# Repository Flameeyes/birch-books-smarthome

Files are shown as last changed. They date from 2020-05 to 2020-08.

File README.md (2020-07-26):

<!--
SPDX-FileCopyrightText: 2020 The birch-books-smarthome Authors

SPDX-License-Identifier: MIT
-->

# Birch Books Smart Home

Lighting up the scene

This repository contains code, schematics, documentation and notes to implement a
MCU-controlled LED lights system for the [LEGO Creator Bookshop
set](https://www.lego.com/en-gb/product/bookshop-10270) (10270).

## Further References

Refer to my [blog posts](https://flameeyes.blog/tag/birch-books/) for details.

You can see some pictures of the results on [my Flickr
album](https://www.flickr.com/photos/flameeyes/albums/72157714292772872).

## License

Copyright 2020 The birch-books-smarthome authors.

Permission is hereby granted, free of charge, to any person obtaining a copy of this
software and associated documentation files (the "Software"), to deal in the Software
without restriction, including without limitation the rights to use, copy, modify,
merge, publish, distribute, sublicense, and/or sell copies of the Software, and to
permit persons to whom the Software is furnished to do so, subject to the following
conditions:

The above copyright notice and this permission notice shall be included in all copies or
substantial portions of the Software.

THE SOFTWARE IS PROVIDED "AS IS", WITHOUT WARRANTY OF ANY KIND, EXPRESS OR IMPLIED,
INCLUDING BUT NOT LIMITED TO THE WARRANTIES OF MERCHANTABILITY, FITNESS FOR A PARTICULAR
PURPOSE AND NONINFRINGEMENT. IN NO EVENT SHALL THE AUTHORS OR COPYRIGHT HOLDERS BE
LIABLE FOR ANY CLAIM, DAMAGES OR OTHER LIABILITY, WHETHER IN AN ACTION OF CONTRACT, TORT
OR OTHERWISE, ARISING FROM, OUT OF OR IN CONNECTION WITH THE SOFTWARE OR THE USE OR
OTHER DEALINGS IN THE SOFTWARE.

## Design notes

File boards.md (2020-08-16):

<!--
SPDX-FileCopyrightText: 2020 The birch-books-smarthome Authors

SPDX-License-Identifier: MIT
-->

# Board Description

For the Birch Books Smart Home project I decided to design the system with two type of
boards: an actuation board, and a controller board. The reason for the split design is
that the controller board can be replaced with alternative implementations without
requiring a new set of wiring for the LEDs.

## Actuation Board

The Actuation Board is a separate board component that bridges the logic in the
controller with the inputs and outputs, and can be used with different controller board
designs as well.

The actuation board is as simple as it can be:

  * 3× pushbuttons (`RST`, `TEST`, `FF`);
  * 3× 1kΩ resistors for pull-down;
  * 2× ULN2003AD Darlington Array;
  * 14× 47Ω resistors, or 2× bussed 7-port resistor networks, for the LEDs.

Two connectors are also present: a 1x20, breadboard compatible header to connect to the
controller board, and a 2×15 connector to connect to the LEDs.

### MCU Connector

| Pin(s) | Description |
| --- | --- |
| 1 | +5V DC |
|  2~15  | LED status (HIGH is ON) |
| 16 | FF input (HIGH is ON) |
| 17 | TEST input (HIGH is ON) |
| 18 | RST input (HIGH is ON)  |
| 19 | VIO (logic HIGH) |
| 20 | GND |

Note that the connector has both a fixed +5V and a VIO, to allow controller boards using
+3.3V CMOS levels for input/output.

As the board was originally designed for 8051 MCUs, the RST line is *active HIGH*, which
is unusual. To connect it to an active-low RST pin, consider using a NPN transistor.

## Controller Boards

Multiple controller boards are present in this repository, with different level of test.

### 8051/8052 (Partly Tested)

This is the original controller board. It was designed with an STC89C52 MCU in mind (a
modern 8052 implementation), and as such it has the UART marked as `ISP_STC` on board
itself.

It includes an optionally-populated CP2104 USB-to-UART chip (and related passives) to
make the programming easier. But it has not been tested since I failed to program a new
chip with the correct firmware.

The firmware for this board is in `8051/`.

### Trinket M0 with MCP23016/17 (In Use)

This version of the controller is designed to work with an [Adafruit Trinket
M0](https://www.adafruit.com/product/3500) board on top.

There are two separate boards in the directory, which are based around the same design
and firmware, but with different GPIO Expanders on them. It's recommended to use the
**MCP23017** version, which has two fewer components and is more reliable.

Both boards have marking and can be technically adapted to use any MCU that supports I²C
and has drivers for the MCP23016/17 series adapters. The needed lines are +5V, VIO (e.g.
3.3V), GND, SDA, SCL, ¬RST.

The firmware for this board is in `circuitpython/`.

### ATmega48

This version of the controller is designed to work with
[ATmega48](https://www.microchip.com/wwwproducts/en/ATmega48) and
[ATmega328](https://www.microchip.com/wwwproducts/en/ATmega328) (the latter untested).

This board is a compromise between the 8051 and Trinket M0 options: it include a simple
8-bit MCU, requiring no passive components, but also an inverter for the RST line.

The ISP header should be compatible with many ATmega programmers, as it exposes the SPI
bus together with the reset and power lines, and is configured as follows:

| Pin | Description |
| --- | --- |
|  1  | SIO |
|  2  | +5V |
|  3  | SCK |
|  4  | SDO |
|  5  | RST |
|  6  | GND |

Note that there is no CS line.

The firmware for this board is in `atmega48/` and should be **source** compatible with
ATmega328, but might require Makefile changes.

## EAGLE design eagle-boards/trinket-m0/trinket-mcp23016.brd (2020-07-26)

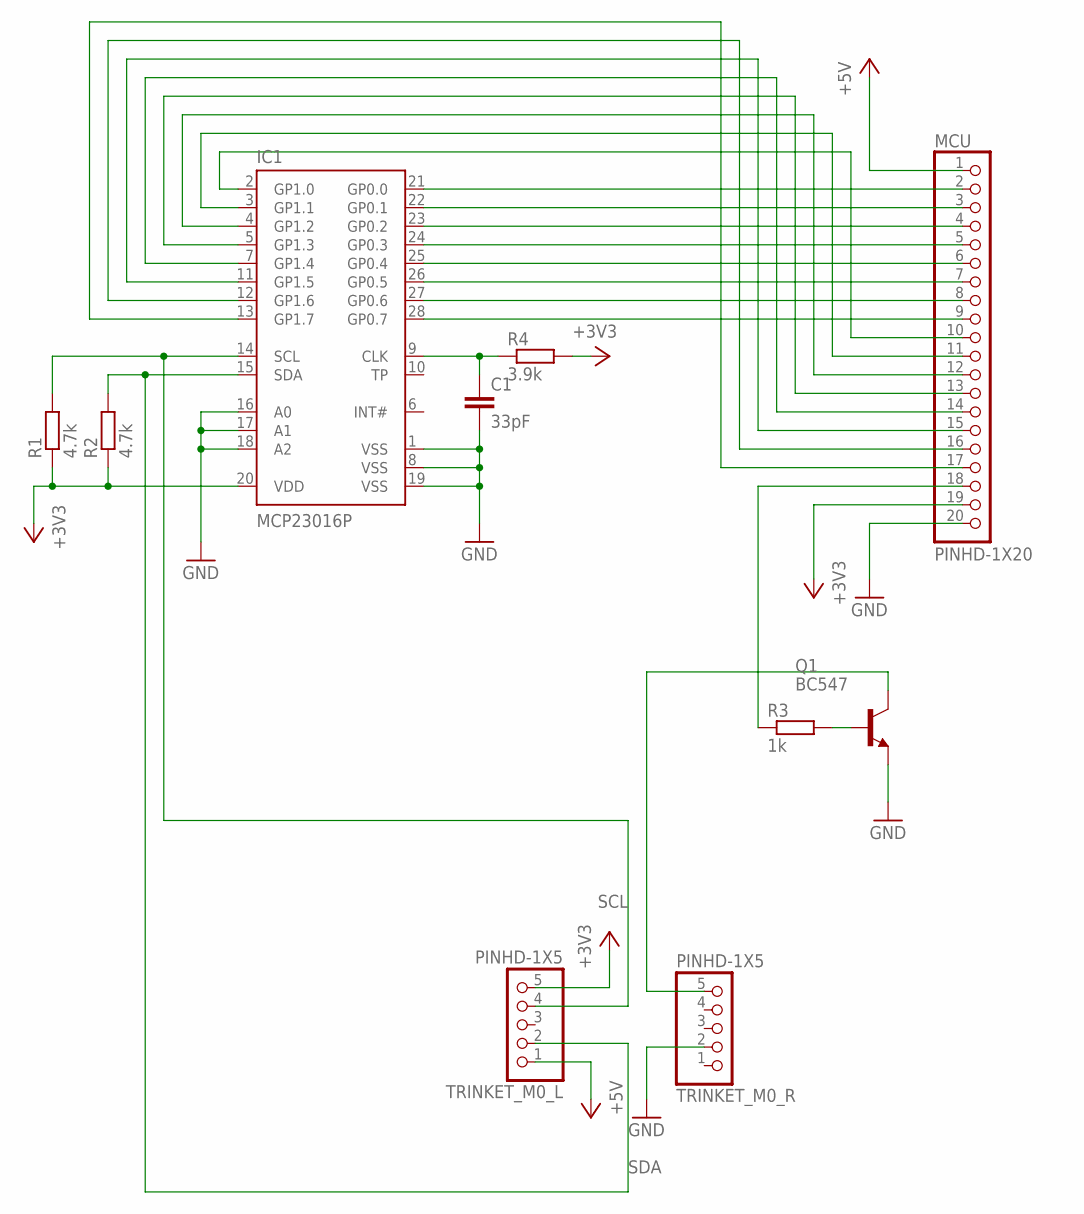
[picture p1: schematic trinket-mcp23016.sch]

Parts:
C1: 33pF; C025-025X050
IC1: MCP23016P; DIL28-3
MCU: PINHD-1X20; 1X20
Q1: BC547; TO92
R1, R2: 4.7k; 0207/10
R3: 1k; 0207/10
R4: 3.9k; 0207/10
TRINKET_M0_L, TRINKET_M0_R: PINHD-1X5; 1X05

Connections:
+3V3: IC1.20 (VDD), MCU.19, R1.1, R2.1, R4.2, TRINKET_M0_L.5
+5V: MCU.1, TRINKET_M0_L.1
GND: C1.2, IC1.1 (VSS), IC1.8 (VSS), IC1.16 (A0), IC1.17 (A1), IC1.18 (A2), IC1.19 (VSS), MCU.20, Q1.1 (E), TRINKET_M0_R.2
unnamed: IC1.21 (GP0.0), MCU.2
unnamed: IC1.22 (GP0.1), MCU.3
unnamed: IC1.23 (GP0.2), MCU.4
unnamed: IC1.24 (GP0.3), MCU.5
unnamed: IC1.25 (GP0.4), MCU.6
unnamed: IC1.26 (GP0.5), MCU.7
unnamed: IC1.27 (GP0.6), MCU.8
unnamed: IC1.28 (GP0.7), MCU.9
unnamed: IC1.2 (GP1.0), MCU.10
unnamed: IC1.3 (GP1.1), MCU.11
unnamed: IC1.4 (GP1.2), MCU.12
unnamed: IC1.5 (GP1.3), MCU.13
unnamed: IC1.7 (GP1.4), MCU.14
unnamed: IC1.11 (GP1.5), MCU.15
unnamed: IC1.12 (GP1.6), MCU.16
unnamed: IC1.13 (GP1.7), MCU.17
unnamed: Q1.2 (B), R3.2
unnamed: MCU.18, R3.1
unnamed: Q1.3 (C), TRINKET_M0_R.5
unnamed: C1.1, IC1.9 (CLK), R4.1
SCL: IC1.14 (SCL), R1.2, TRINKET_M0_L.4
SDA: IC1.15 (SDA), R2.2, TRINKET_M0_L.2

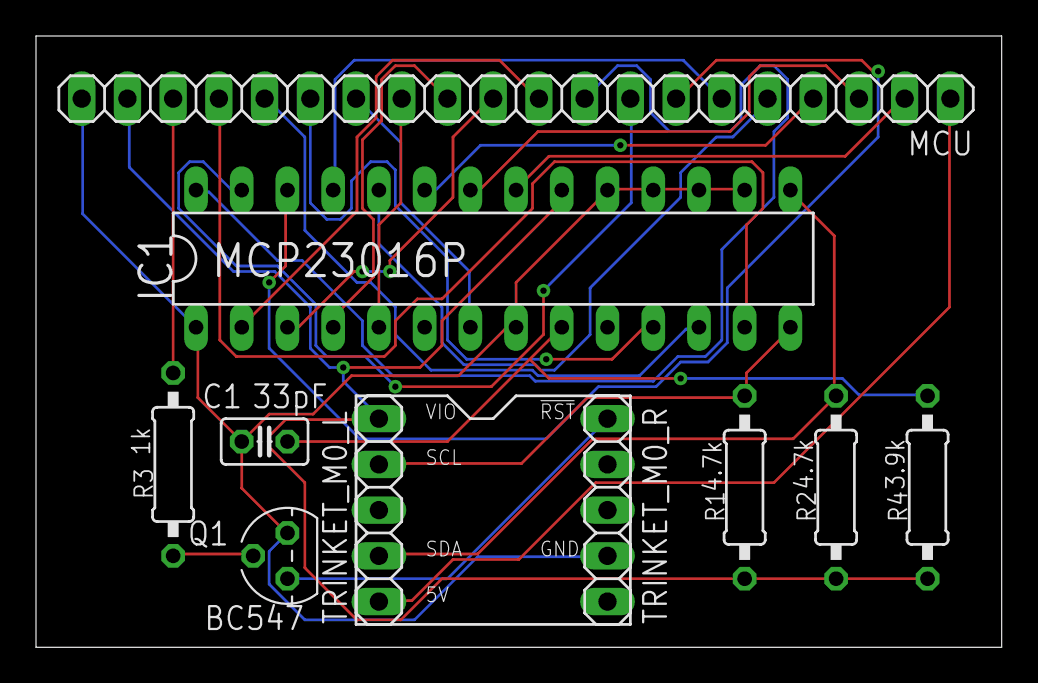
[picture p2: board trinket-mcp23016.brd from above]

Board: 2 copper layers, 53.6 x 34.0 mm, 10 parts (0 on the bottom side), 25 nets.

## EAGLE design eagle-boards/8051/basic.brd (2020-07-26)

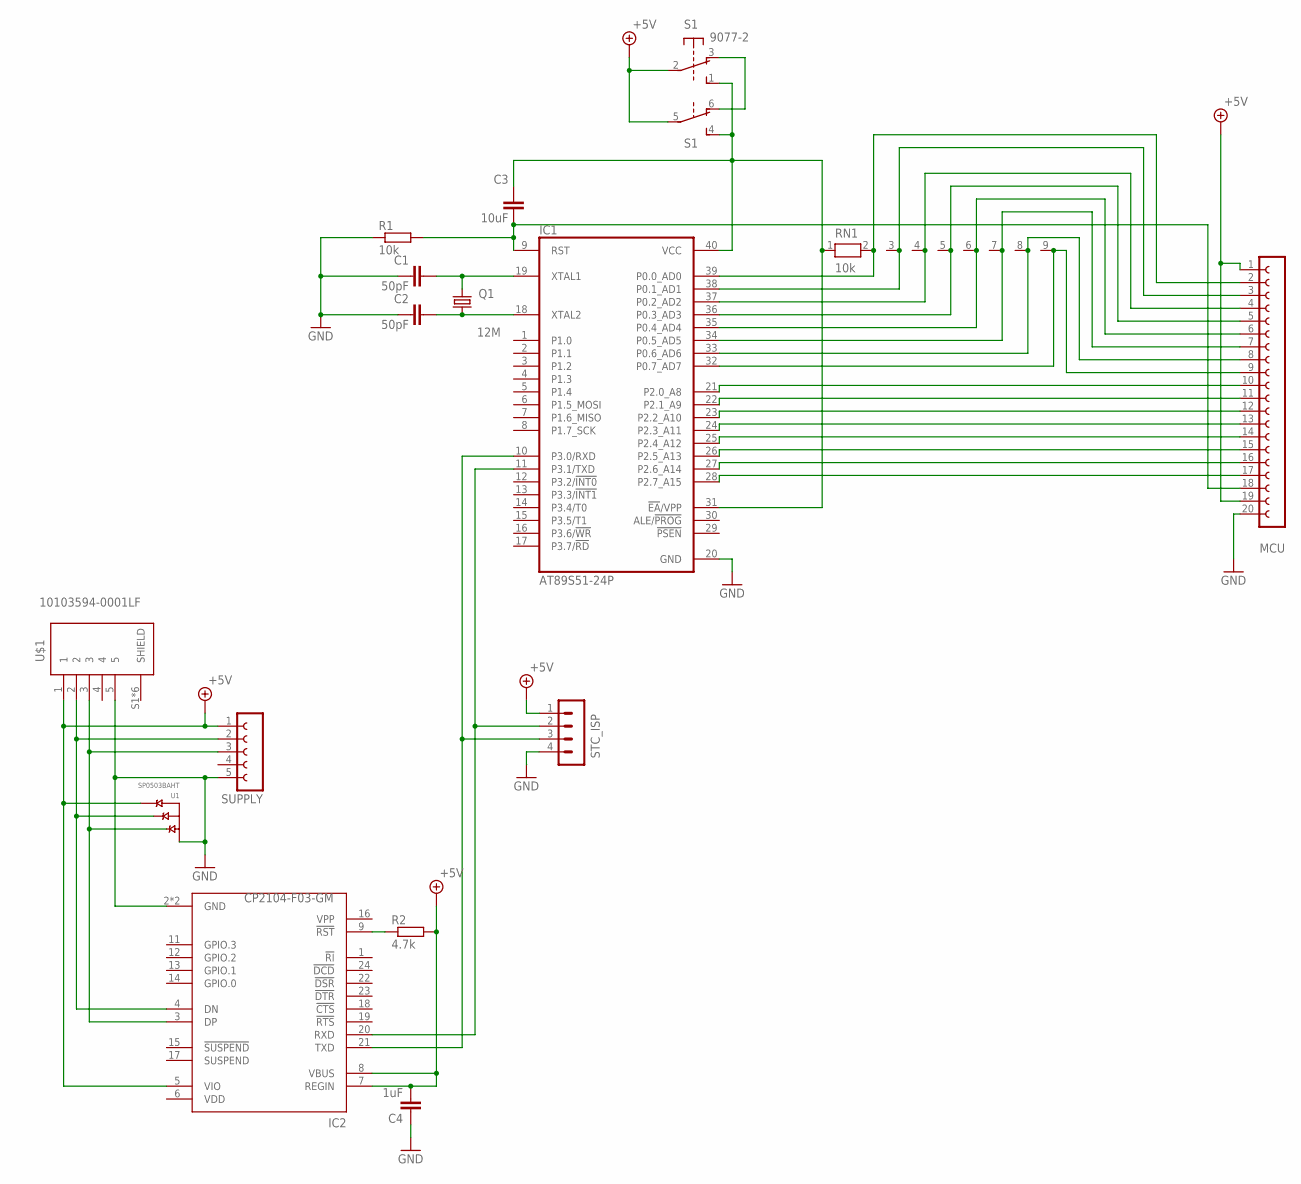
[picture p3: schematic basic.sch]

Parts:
C1, C2: 50pF; C050-025X075
C3: 10uF; C025-025X050
C4: 1uF; C025-025X050
IC1: AT89S51-24P; DIL40
IC2: CP2104-F03-GM; QFN50P400X400X80-25N
MCU: FE20-1; FE20
Q1: 12M; HC49U70
R1: 10k; 0207/10
R2: 4.7k; 0207/10
RN1: 10k; RN-9
S1: 9077-2
STC_ISP: MA04-1
SUPPLY: FE05-1
U1: SP0503BAHT; SOT143
U$1: 10103594-0001LF; FCI_10103594-0001LF

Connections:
+5V: C4.2, IC2.5 (VIO), IC2.7 (REGIN), IC2.8 (VBUS), MCU.1, MCU.19, R2.2, S1.2, S1.5, STC_ISP.1, SUPPLY.1, U1.4 (C), U$1.1
GND: C1.1, C2.1, C4.1, IC1.20 (GND), IC2.2 (GND), IC2.25 (GND), MCU.20, R1.1, STC_ISP.4, SUPPLY.5, U1.1 (GND), U$1.5
unnamed: IC2.4 (DN), SUPPLY.2, U1.3 (B), U$1.2
unnamed: IC1.28 (P2.7_A15), MCU.17
unnamed: C1.2, IC1.19 (XTAL1), Q1.2
unnamed: C2.2, IC1.18 (XTAL2), Q1.1
unnamed: C3.2, IC1.9 (RST), MCU.18, R1.2
unnamed: IC1.27 (P2.6_A14), MCU.16
unnamed: IC1.38 (P0.1_AD1), MCU.3, RN1.3
unnamed: IC1.26 (P2.5_A13), MCU.15
unnamed: IC1.25 (P2.4_A12), MCU.14
unnamed: IC1.36 (P0.3_AD3), MCU.5, RN1.5
unnamed: IC1.35 (P0.4_AD4), MCU.6, RN1.6
unnamed: IC1.34 (P0.5_AD5), MCU.7, RN1.7
unnamed: IC1.33 (P0.6_AD6), MCU.8, RN1.8
unnamed: IC1.32 (P0.7_AD7), MCU.9, RN1.9
unnamed: IC1.24 (P2.3_A11), MCU.13
unnamed: IC1.23 (P2.2_A10), MCU.12
unnamed: IC1.22 (P2.1_A9), MCU.11
unnamed: IC1.10 (P3.0/RXD), IC2.21 (TXD), STC_ISP.3
unnamed: IC1.21 (P2.0_A8), MCU.10
unnamed: IC2.3 (DP), SUPPLY.3, U1.2 (A), U$1.3
unnamed: IC1.37 (P0.2_AD2), MCU.4, RN1.4
unnamed: S1.3 (O), S1.6 (O)
unnamed: IC2.9 (!RST!), R2.1
unnamed: IC1.39 (P0.0_AD0), MCU.2, RN1.2
unnamed: C3.1, IC1.31 (!EA!/VPP), IC1.40 (VCC), RN1.1, S1.1 (S), S1.4 (S)
unnamed: IC1.11 (P3.1/TXD), IC2.20 (RXD), STC_ISP.2
VDD: IC2.6 (VDD)

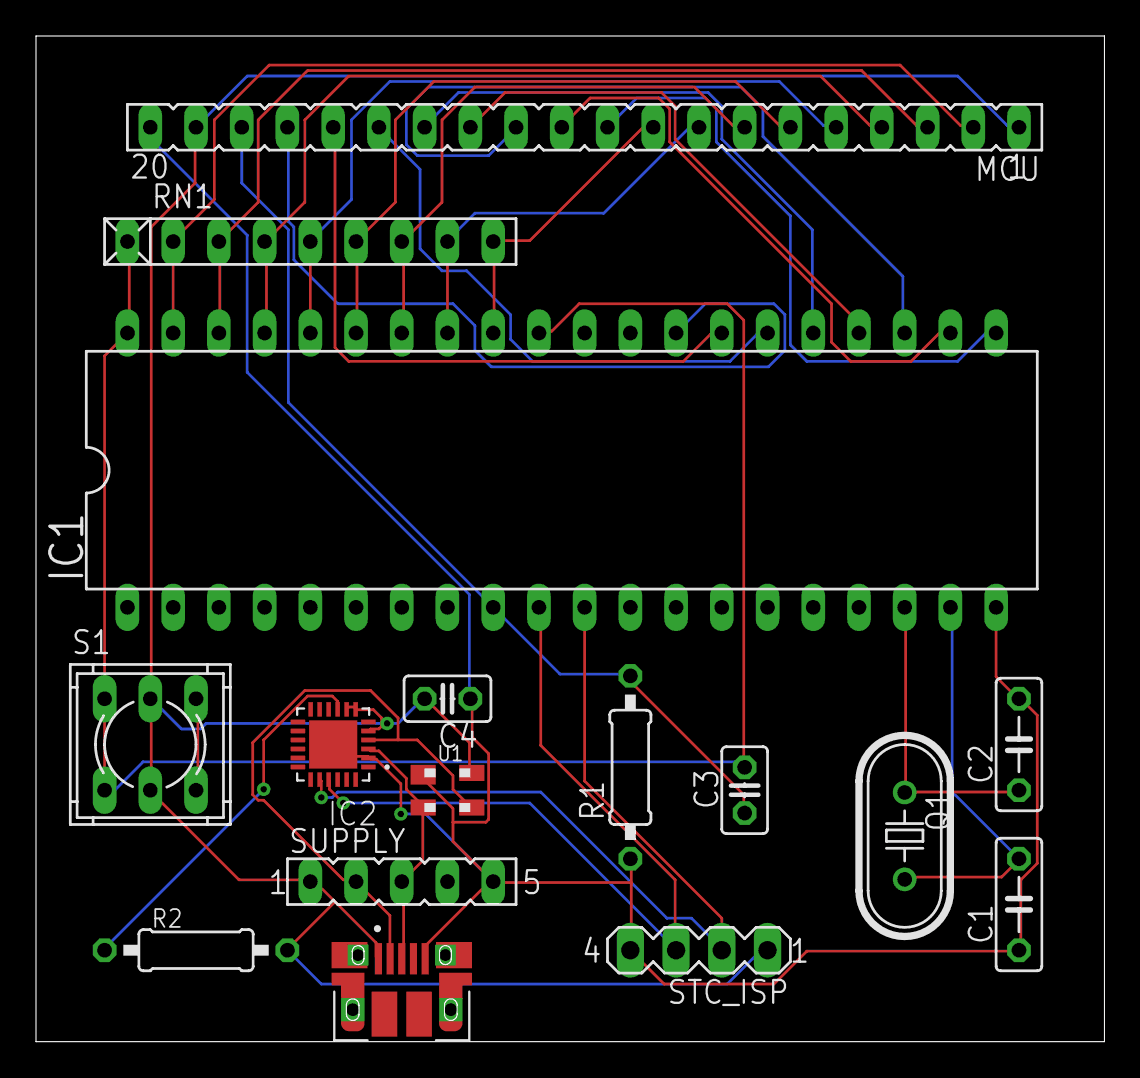
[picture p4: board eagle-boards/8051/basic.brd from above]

Board: 2 copper layers, 59.4 x 55.9 mm, 16 parts (0 on the bottom side), 28 nets.

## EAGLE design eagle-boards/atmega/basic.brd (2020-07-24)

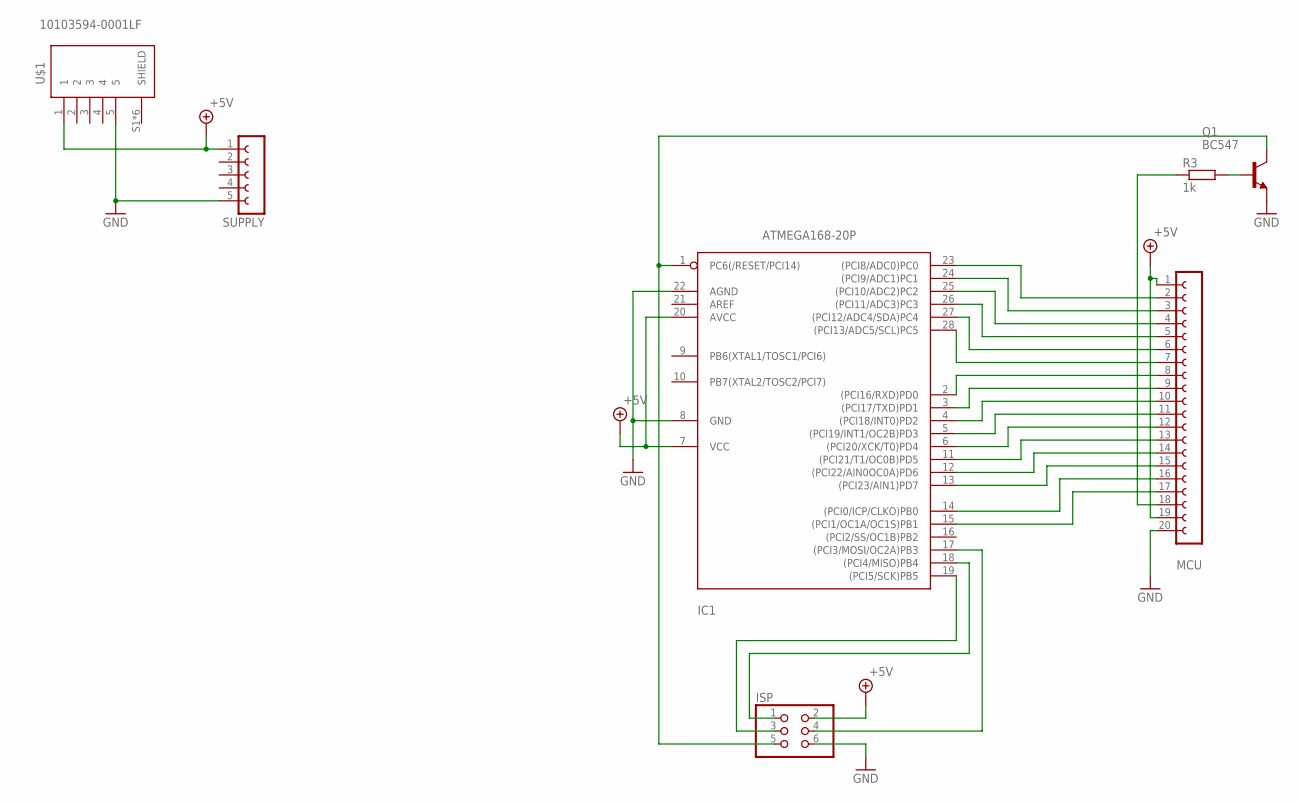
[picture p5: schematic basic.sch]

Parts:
IC1: ATMEGA168-20P; DIL28-3
ISP: PINHD-2X3; 2X03
MCU: FE20-1; FE20
Q1: BC547; TO92
R3: 1k; 0207/10
SUPPLY: FE05-1
U$1: 10103594-0001LF; FCI_10103594-0001LF

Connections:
+5V: IC1.7 (VCC), IC1.20 (AVCC), ISP.2, MCU.1, MCU.19, SUPPLY.1, U$1.1
GND: IC1.8 (GND), IC1.22 (AGND), ISP.6, MCU.20, Q1.1 (E), SUPPLY.5, U$1.5
unnamed: IC1.17 ((PCI3/MOSI/OC2A)PB3), ISP.4
unnamed: MCU.18, R3.1
unnamed: IC1.18 ((PCI4/MISO)PB4), ISP.1
unnamed: IC1.19 ((PCI5/SCK)PB5), ISP.3
unnamed: IC1.23 ((PCI8/ADC0)PC0), MCU.2
unnamed: IC1.24 ((PCI9/ADC1)PC1), MCU.3
unnamed: IC1.25 ((PCI10/ADC2)PC2), MCU.4
unnamed: IC1.26 ((PCI11/ADC3)PC3), MCU.5
unnamed: IC1.27 ((PCI12/ADC4/SDA)PC4), MCU.6
unnamed: IC1.28 ((PCI13/ADC5/SCL)PC5), MCU.7
unnamed: IC1.2 ((PCI16/RXD)PD0), MCU.8
unnamed: IC1.3 ((PCI17/TXD)PD1), MCU.9
unnamed: IC1.4 ((PCI18/INT0)PD2), MCU.10
unnamed: IC1.5 ((PCI19/INT1/OC2B)PD3), MCU.11
unnamed: IC1.6 ((PCI20/XCK/T0)PD4), MCU.12
unnamed: IC1.11 ((PCI21/T1/OC0B)PD5), MCU.13
unnamed: Q1.2 (B), R3.2
unnamed: IC1.12 ((PCI22/AIN0OC0A)PD6), MCU.14
unnamed: IC1.1 (PC6(/RESET/PCI14)), ISP.5, Q1.3 (C)
unnamed: IC1.13 ((PCI23/AIN1)PD7), MCU.15
unnamed: IC1.14 ((PCI0/ICP/CLKO)PB0), MCU.16
unnamed: IC1.15 ((PCI1/OC1A/OC1S)PB1), MCU.17

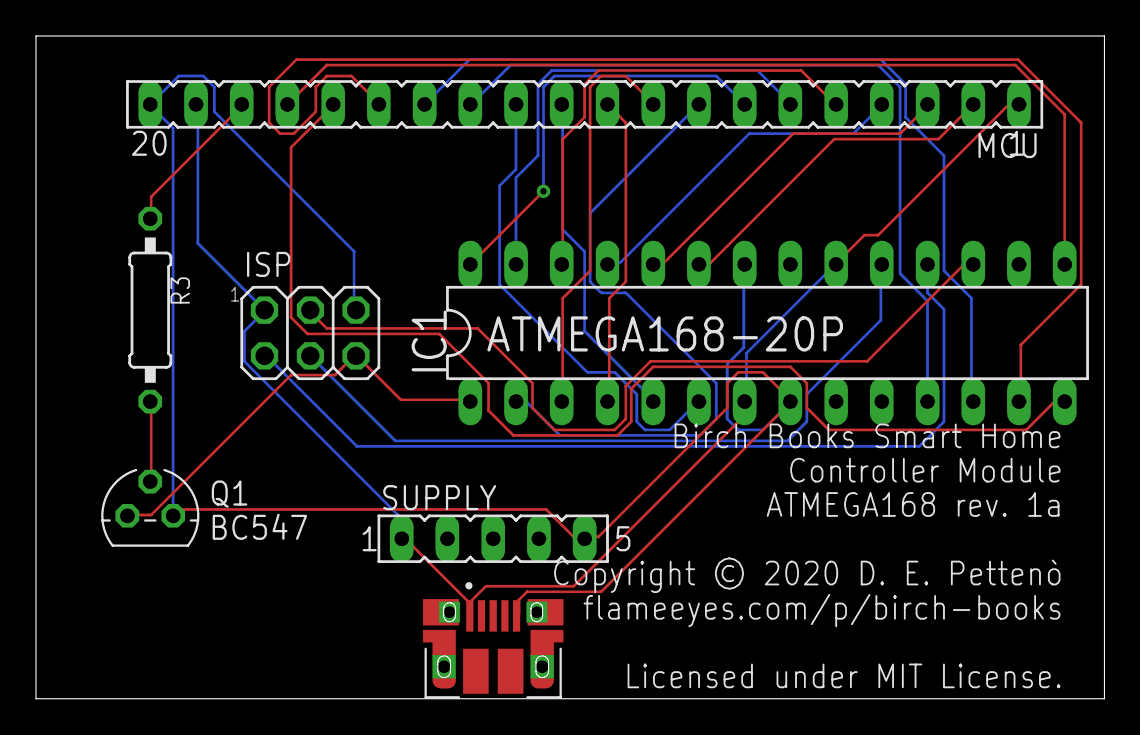
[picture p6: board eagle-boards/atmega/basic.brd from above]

Board: 2 copper layers, 59.4 x 36.8 mm, 7 parts (0 on the bottom side), 24 nets.

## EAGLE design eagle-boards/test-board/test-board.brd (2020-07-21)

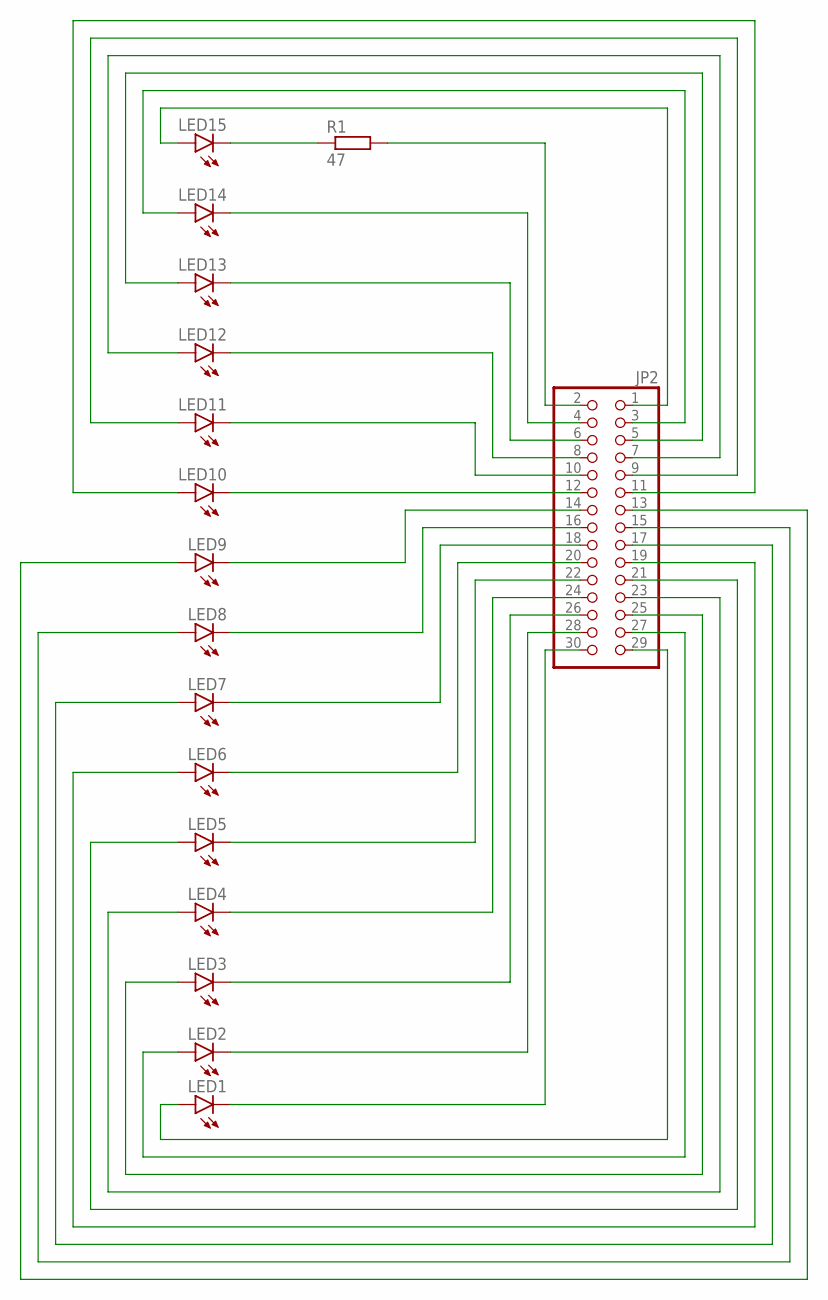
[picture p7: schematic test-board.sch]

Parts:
JP2: PINHD-2X15; 2X15
LED1, LED2, LED3, LED4, LED5, LED6, LED7, LED8, LED9, LED10, LED11, LED12, LED13, LED14, LED15: LED5MM
R1: 47; 0207/10

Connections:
unnamed: JP2.2, R1.2
unnamed: JP2.4, LED14.K (C)
unnamed: JP2.6, LED13.K (C)
unnamed: JP2.8, LED12.K (C)
unnamed: JP2.10, LED11.K (C)
unnamed: JP2.12, LED10.K (C)
unnamed: JP2.30, LED1.K (C)
unnamed: JP2.28, LED2.K (C)
unnamed: JP2.26, LED3.K (C)
unnamed: JP2.24, LED4.K (C)
unnamed: JP2.22, LED5.K (C)
unnamed: JP2.20, LED6.K (C)
unnamed: JP2.18, LED7.K (C)
unnamed: JP2.16, LED8.K (C)
unnamed: JP2.14, LED9.K (C)
unnamed: JP2.1, LED15.A
unnamed: JP2.3, LED14.A
unnamed: JP2.5, LED13.A
unnamed: JP2.7, LED12.A
unnamed: JP2.9, LED11.A
unnamed: JP2.11, LED10.A
unnamed: JP2.29, LED1.A
unnamed: JP2.27, LED2.A
unnamed: JP2.25, LED3.A
unnamed: JP2.23, LED4.A
unnamed: JP2.21, LED5.A
unnamed: JP2.19, LED6.A
unnamed: JP2.17, LED7.A
unnamed: JP2.15, LED8.A
unnamed: JP2.13, LED9.A
unnamed: LED15.K (C), R1.1

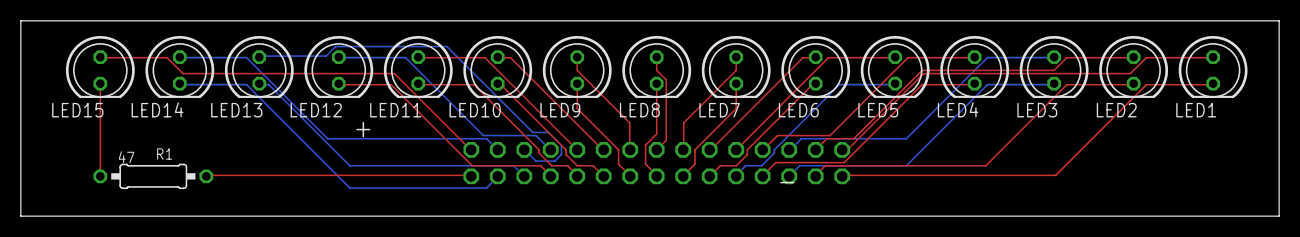
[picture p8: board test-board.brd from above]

Board: 2 copper layers, 120.6 x 18.7 mm, 17 parts (1 on the bottom side), 31 nets.

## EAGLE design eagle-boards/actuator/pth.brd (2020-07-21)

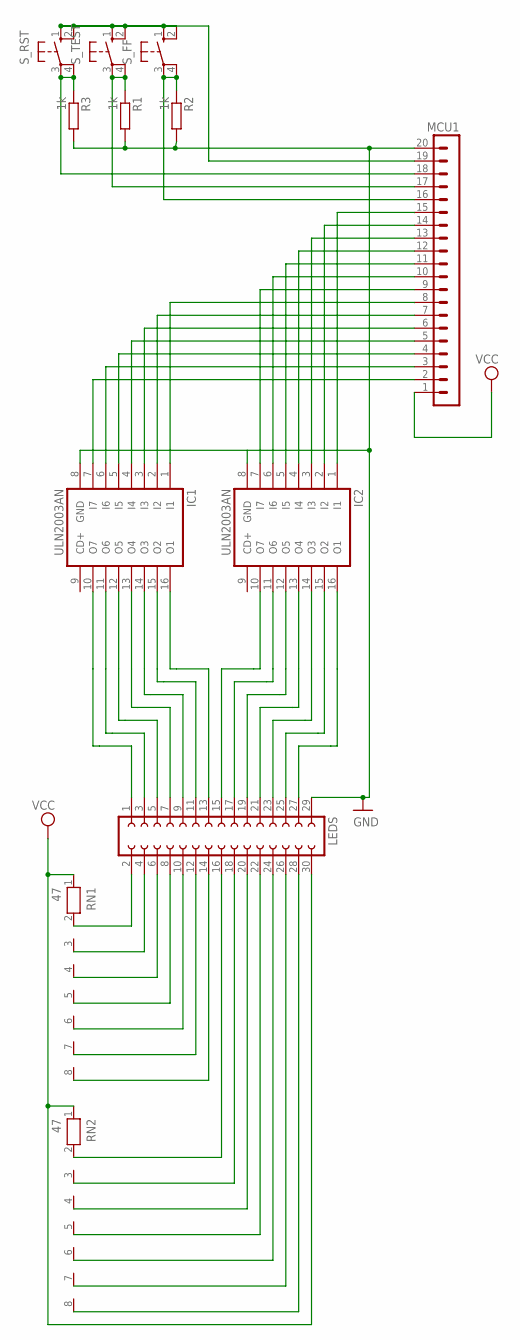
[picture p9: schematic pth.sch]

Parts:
IC1, IC2: ULN2003AN; DIL16
LEDS: FE15-2
MCU1: MA20-1
R1, R2, R3: 1k; 0207/10
RN1, RN2: 47; RN-8
S_FF: 10-XX; B3F-10XX
S_RST: 10-XX; B3F-10XX
S_TEST: 10-XX; B3F-10XX

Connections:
GND: IC1.8 (GND), IC2.8 (GND), LEDS.29, MCU1.20, R1.2, R2.2, R3.2
unnamed: IC1.1 (I1), MCU1.8
unnamed: MCU1.19, S_FF.1 (S), S_FF.2 (S1), S_RST.1 (S), S_RST.2 (S1), S_TEST.1 (S), S_TEST.2 (S1)
unnamed: IC1.7 (I7), MCU1.2
unnamed: IC1.6 (I6), MCU1.3
unnamed: IC1.5 (I5), MCU1.4
unnamed: IC1.4 (I4), MCU1.5
unnamed: IC1.3 (I3), MCU1.6
unnamed: IC1.2 (I2), MCU1.7
unnamed: IC2.7 (I7), MCU1.9
unnamed: IC2.6 (I6), MCU1.10
unnamed: IC2.5 (I5), MCU1.11
unnamed: IC2.4 (I4), MCU1.12
unnamed: IC2.3 (I3), MCU1.13
unnamed: IC2.2 (I2), MCU1.14
unnamed: IC2.1 (I1), MCU1.15
unnamed: LEDS.2, RN1.2
unnamed: MCU1.18, R3.1, S_RST.3, S_RST.4 (P1)
unnamed: MCU1.17, R1.1, S_TEST.3, S_TEST.4 (P1)
unnamed: MCU1.16, R2.1, S_FF.3, S_FF.4 (P1)
unnamed: IC2.16 (O1), LEDS.27
unnamed: IC2.15 (O2), LEDS.25
unnamed: IC2.14 (O3), LEDS.23
unnamed: IC2.13 (O4), LEDS.21
unnamed: IC2.12 (O5), LEDS.19
unnamed: IC2.11 (O6), LEDS.17
unnamed: IC2.10 (O7), LEDS.15
unnamed: IC1.16 (O1), LEDS.13
unnamed: IC1.15 (O2), LEDS.11
unnamed: IC1.14 (O3), LEDS.9
unnamed: IC1.13 (O4), LEDS.7
unnamed: IC1.12 (O5), LEDS.5
unnamed: IC1.11 (O6), LEDS.3
unnamed: IC1.10 (O7), LEDS.1
unnamed: LEDS.4, RN1.3
unnamed: LEDS.6, RN1.4
unnamed: LEDS.8, RN1.5
unnamed: LEDS.10, RN1.6
unnamed: LEDS.12, RN1.7
unnamed: LEDS.14, RN1.8
unnamed: LEDS.16, RN2.2
unnamed: LEDS.18, RN2.3
unnamed: LEDS.20, RN2.4
unnamed: LEDS.22, RN2.5
unnamed: LEDS.24, RN2.6
unnamed: LEDS.26, RN2.7
unnamed: LEDS.28, RN2.8
VCC: LEDS.30, MCU1.1, RN1.1, RN2.1

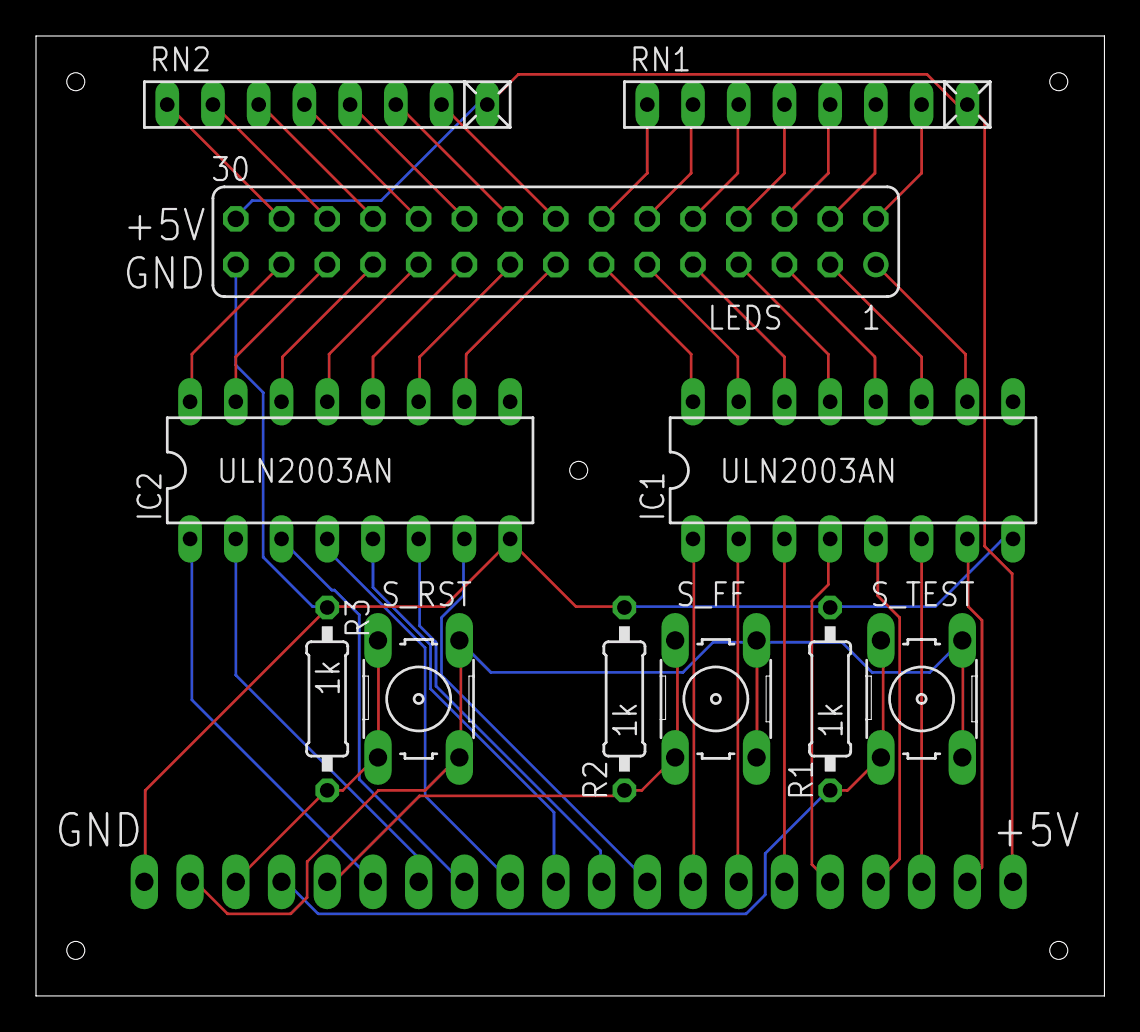
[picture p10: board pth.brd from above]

Board: 2 copper layers, 59.4 x 53.3 mm, 12 parts (1 on the bottom side), 48 nets.

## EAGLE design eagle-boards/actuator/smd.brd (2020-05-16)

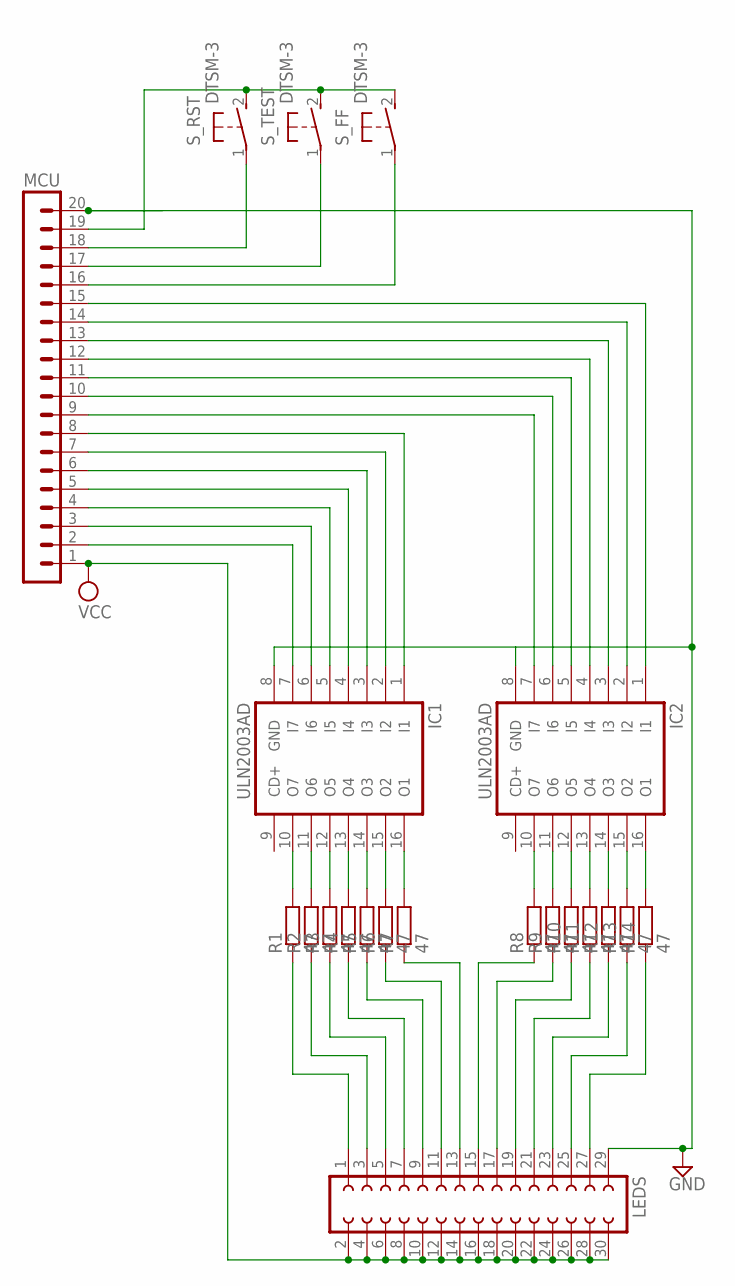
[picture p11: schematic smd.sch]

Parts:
IC1, IC2: ULN2003AD; SO16
LEDS: FE15-2
MCU: MA20-1
R1, R2, R3, R4, R5, R6, R7, R8, R9, R10, R11, R12, R13, R14: 47; M0805
S_FF: DTSM-3
S_RST: DTSM-3
S_TEST: DTSM-3

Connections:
GND: IC1.8 (GND), IC2.8 (GND), LEDS.29, MCU.20
unnamed: IC1.1 (I1), MCU.8
unnamed: MCU.19, S_FF.2, S_RST.2, S_TEST.2
unnamed: IC1.7 (I7), MCU.2
unnamed: IC1.6 (I6), MCU.3
unnamed: IC1.5 (I5), MCU.4
unnamed: IC1.4 (I4), MCU.5
unnamed: IC1.3 (I3), MCU.6
unnamed: IC1.2 (I2), MCU.7
unnamed: IC2.7 (I7), MCU.9
unnamed: IC2.6 (I6), MCU.10
unnamed: IC2.5 (I5), MCU.11
unnamed: IC2.4 (I4), MCU.12
unnamed: IC2.3 (I3), MCU.13
unnamed: IC2.2 (I2), MCU.14
unnamed: IC2.1 (I1), MCU.15
unnamed: MCU.18, S_RST.1
unnamed: MCU.17, S_TEST.1
unnamed: MCU.16, S_FF.1
unnamed: IC1.10 (O7), R1.2
unnamed: IC1.11 (O6), R2.2
unnamed: IC1.12 (O5), R3.2
unnamed: IC1.13 (O4), R4.2
unnamed: IC1.14 (O3), R5.2
unnamed: IC1.15 (O2), R6.2
unnamed: IC1.16 (O1), R7.2
unnamed: IC2.10 (O7), R8.2
unnamed: IC2.11 (O6), R9.2
unnamed: IC2.12 (O5), R10.2
unnamed: IC2.13 (O4), R11.2
unnamed: IC2.14 (O3), R12.2
unnamed: IC2.15 (O2), R13.2
unnamed: IC2.16 (O1), R14.2
unnamed: LEDS.27, R14.1
unnamed: LEDS.25, R13.1
unnamed: LEDS.23, R12.1
unnamed: LEDS.21, R11.1
unnamed: LEDS.19, R10.1
unnamed: LEDS.17, R9.1
unnamed: LEDS.15, R8.1
unnamed: LEDS.13, R7.1
unnamed: LEDS.11, R6.1
unnamed: LEDS.9, R5.1
unnamed: LEDS.7, R4.1
unnamed: LEDS.5, R3.1
unnamed: LEDS.3, R2.1
unnamed: LEDS.1, R1.1
VCC: LEDS.2, LEDS.4, LEDS.6, LEDS.8, LEDS.10, LEDS.12, LEDS.14, LEDS.16, LEDS.18, LEDS.20, LEDS.22, LEDS.24, LEDS.26, LEDS.28, LEDS.30, MCU.1

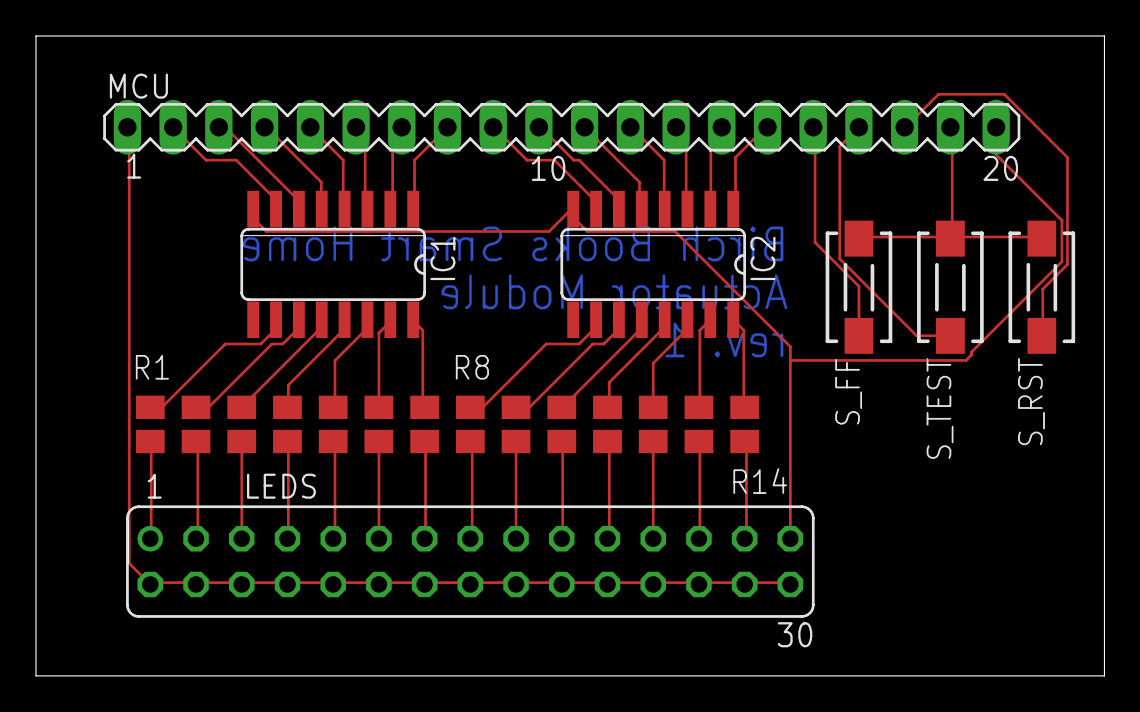
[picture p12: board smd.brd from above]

Board: 2 copper layers, 59.4 x 35.5 mm, 21 parts (0 on the bottom side), 48 nets.

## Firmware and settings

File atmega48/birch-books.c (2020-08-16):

// SPDX-FileCopyrightText: © 2020 The birch-books-smarthome Authors
// SPDX-License-Identifier: MIT

#define F_CPU 1000000

#include <stdbool.h>

#include <avr/interrupt.h>
#include <avr/io.h>
#include <util/delay.h>

#include "schedule.h"

volatile uint16_t ticktime = 0;
volatile bool fastclock = false;

volatile bool testmode = false;

#define TEST_PRESSED (PINB & (1 << PINB1))
#define FF_PRESSED (PINB & (1 << PINB0))

ISR(TIMER1_COMPA_vect) {

  /* If the main loop set the fastclock flag, increase the tick count by 64.
   *
   * This means that for each 62.5msec we actually record 4 seconds having
   * passed. This "fast forward" should complete the schedule within a minute
   * rather than an hour.
   */
  uint8_t tickvalue = fastclock ? 64 : 1;

  /* We let the ticktime overflow transparently, from 65535 back to 0.
   * This simplifies our code quite a bit as we don't need to divide anything.
   */
  ticktime += tickvalue;
}

/* Return the internal timer in ticks (1/16th of a second).
 *
 * The only difference to accessing ticktime directly is that a copy is made
 * while interrupts are disabled, to avoid it changing during access.
 */
static uint16_t ticks() {
  cli();
  uint16_t ctmp = ticktime;
  sei();

  return ctmp;
}

int main() {
  /* Set ports C (0~5) and D (0~7) for output. */
  DDRC |= ((1 << DDC0) | (1 << DDC1) | (1 << DDC2) | (1 << DDC3) | (1 << DDC4) |
           (1 << DDC5));
  DDRD |= ((1 << DDD0) | (1 << DDD1) | (1 << DDD2) | (1 << DDD3) | (1 << DDD4) |
           (1 << DDD5) | (1 << DDD6) | (1 << DDD7));

  /* Run a LED self-test at start, for just a second. Do this before setting up
   * timers, so that the timer starts counting from 0. */
  PORTC = 0xFF;
  PORTD = 0xFF;
  _delay_ms(1000);

  /* Set ports to zero. */
  PORTC = 0;
  PORTD = 0;

  /* Set up Timer 1 for 62.5ms. */
  OCR1A = 62499;            // 1/16th of a second at 1MHz clock.
  TCCR1B |= ((1 << CS10)    // Fcpu prescale = 1
             | (1 << WGM12) // CTC mode
  );
  TIMSK1 |= (1 << OCIE1A); // Enable CTC Interrupt
  sei();                   // Enable global interrupts

  /* If TEST is pressed at start, consider us in 'self-test mode': chase a
   * single room through the output port.
   */
  while (TEST_PRESSED) {
    uint16_t clock_secs = ticks() >> 4;
    uint8_t test_index = clock_secs % 10;

    PORTC = test_schedule[test_index] & 0xFF;
    PORTD = test_schedule[test_index] >> 8;
  }

  /* This is the main loop for the firmware.
   *
   * If TEST is pressed, toggle between test mode on or off. Test mode turns on
   * all the of the LEDs at once.
   *
   * Set the `fastclock` flag here in the main loop (so that it doesn't happen
   * during the self-test mode), which increases the ticks in the interrupt.
   */
  for (;;) {
    fastclock = FF_PRESSED;

    if (TEST_PRESSED) {
      testmode = !testmode;

      /* Debounce the TEST keypress.
       *
       * We do this here to make sure we don't see the button-press while we
       * update the outputs. Sounds silly, but at 12MHz it's possible for a
       * human to race the code.
       */
      while (TEST_PRESSED)
        ;
    }

    if (testmode) {
      PORTC = 0xFF;
      PORTD = 0xFF;
    } else {
      /* The schedule is a 16 "hours" schedule with the two ports setting
       * separate environment.
       *
       * We calculate the schedule directly in ticks. There's 256 seconds in a
       * "virtual hour", and since ticks go to 1/16th of a second, this brings
       * us to 4096 ticks per "virtual hour".
       *
       * Unfortunately we need to explicitly express this as a shift, otherwise
       * sdcc generates an integer division function call.
       */
      uint16_t clock_ticks = ticks();
      uint8_t virtual_hour = (clock_ticks >> 12) & 0x0F;

      PORTC = schedule[virtual_hour] & 0xFF;
      PORTD = schedule[virtual_hour] >> 8;
    }
  }
}

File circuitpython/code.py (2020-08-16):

# SPDX-FileCopyrightText: © 2020 The birch-books-smarthome Authors
# SPDX-License-Identifier: MIT

import time

import board
import busio

from adafruit_mcp230xx.mcp23016 import MCP23016
from adafruit_mcp230xx.mcp23017 import MCP23017

import schedule

i2c = busio.I2C(board.SCL, board.SDA)

i2c.try_lock()
i2c_devices = i2c.scan()
i2c.unlock()

if 32 in i2c_devices:
    mcp = MCP23016(i2c)
    print("Found MCP23016 @ 32")
elif 33 in i2c_devices:
    mcp = MCP23017(i2c, address=33)
    print("Found MCP13017 @ 33")
else:
    raise Exception("No GPIO Expander found.")

mcp.iodir = 0xC000

test_pin = mcp.get_pin(15)
ff_pin = mcp.get_pin(14)


def write_gp(value):
    mcp.gpio = value & 0x3FFF


# Run a LED self-test at start, for just a second.
write_gp(0x3FFF)
time.sleep(1)

while test_pin.value:
    print("Entering on-reset test loop.")
    clock_secs = int(time.monotonic())

    write_gp(schedule.TEST_SCHEDULE[clock_secs % 10])
    time.sleep(0)

test_mode = False
virtual_hour = None
counter = 0
while True:
    counter += 1
    time.sleep(0)
    if test_pin.value:
        test_mode = not test_mode
        print("Test mode: %s" % test_mode)
        if test_mode:
            virtual_hour = None
            write_gp(0xFFFF)

        while test_pin.value:
            continue

    if test_mode:
        time.sleep(0)
        continue

    if ff_pin.value:
        seconds_per_virtualhour = 4
    else:
        seconds_per_virtualhour = 240

    monotonic = int(time.monotonic())
    monotonic_hour = monotonic // seconds_per_virtualhour

    new_virtual_hour = monotonic_hour % 16
    if virtual_hour == new_virtual_hour:
        continue
    virtual_hour = new_virtual_hour

    print(
        "It's %d o'clock (%d %d) and all is well."
        % (virtual_hour, monotonic_hour, monotonic)
    )

    write_gp(schedule.SCHEDULE[virtual_hour])

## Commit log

2020-04-04 Import the first basic version of the PCB
    This includes the AutoDesk Eagle files describing a board that includes the two darlington arrays, the connector for the LEDs, control buttons and ISP headers for both the Microchip and STC variants 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
    [basic.brd, basic.sch]
2020-04-06 Split the actuation into its own board.
    Note that the previous design was broken, as the Darlingtons weren't being grounded, but rather joined to Vcc.
    [actuator-module.brd, actuator-module.sch, basic.brd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]
2020-04-09 Fix significant mistakes in the controller board.
    The capacitors to stabilise the crystal need to be a bit beefier, make space for them.
    Replace the pin header with a female header for the connection to the actuator board.
    Necessary: add a resistor network between P0 and the connector.
    P0 is the only port needing pull-up resistors.
    [basic.brd, basic.sch]
2020-04-09 Move boards on a separate directory.
    This allows arranging them by implementation.
    The actuator module is reusable, the 8051 board isn't.
    [actuator-module.brd, actuator-module.sch, basic.brd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]
2020-04-09 Rename actuator-module.
    This allows creating alternative versions of the module. This design is fully SMD, ready for turnkey production.
    But a through-hole solder-at-home allows faster prototyping.
    [smd.brd, smd.sch]
2020-04-09 Add through-hole variant of the actuator board.
    This should make prototyping faster/easier.
    [pth.brd, pth.sch]
2020-04-09 Wire the inputs to logic.
    - While FF is pressed, timer goes 1000x (not final.)
    - If FF is pressed at startup, put a chase light pattern into the ports,
    for testing.
    - If TEST is pressed toggle between all-on and not.
    Note that sdcc is buggy and does not handle logic correctly, or
    functions. Or constants. So use a lot of #define instead and consider this
    glorified asm.
    [birch-books.c]
2020-04-10 Actually write the firmware for the 8051 control board.
    This includes all the expected logic to control the board, and a lot of
    documentation of what's going on.
    Note that this targets in particular the 8051 clones that include Timer 2,
    since it's the easier auto-reload 16-bit implementation, and it includes
    some explicit workarounds for sdcc code generation.
    [birch-books.c]
2020-04-10 Micro-optimization: sdcc doesn't optimise these two operations the same way.
    [birch-books.c]
2020-04-10 Micro-optimisation: avoid jump in self-test mode.
    [birch-books.c]
2020-04-15 Improve documentation of the boards.
2020-04-23 Move the 8051 build out of the fw/ directory.
    I moved the boards onto a different structure anyway.
2020-04-23 Invert house bedroom lamp and light lines.
    [birch-books.c]
2020-05-16 Fix up trailing whitespace.
    [basic.brd, basic.sch, pth.brd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]
2020-07-18 New revision for the STC89C52 controller board.
    Include (optional) CP2104 USB-to-UART adapter to make it easier to program the board in-system.
    Include a latching pushbutton for power, which is also needed to work correctly for in-system programming.
    [basic.brd, basic.sch]
2020-07-18 New revision for the actuator board.
    Fix orientation of buttons to be the same between all three, and include pull-down resistors if the input lines are not pulled down.
    [pth.brd, pth.sch]
2020-07-18 Add a test board for the actuator board.
    This allows testing the actuator without wiring the whole LEGO set harness up.
    [test-board.brd, test-board.sch]
2020-07-18 Introduce Adafruit Trinket M0-based controller boards.
    The two boards are pretty much identical except for the GPIO expander used:
    - MCP23016 is an old, deprecated chip, but still found on the market, it needs two more passives to work and doesn't offer pull-up or pull-downs for inputs. It requires a non-main branch version of the MCP230xx library at the time of committing this.
    - MCP23017 is more recent and recommended; it's supported out of the box by the MCP230xx library. For it to be supported with the same CircuitPython code, the board puts it on non-default address 33.
    [trinket-mcp23016.brd, trinket-mcp23016.sch, trinket-mcp23017.brd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]
2020-07-18 Untested version of an ATmega48-based controller board.
    This is untested, but should allow using an ATmega48 in a similar way to how the STC89 is used.
    [basic.brd, basic.sch]
2020-07-18 Fix whitespace for pre-commit.
    [basic.brd, basic.sch, pth.brd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]
2020-07-18 Add SPDX license attachments for the Eagle Boards.
2020-07-18 Add CircuitPython-based implementation.
    This requires a modified adafruit_mcp230xx library that supports the MCP23016, but it will work with both the '16 and '17 boards (on different I2C addresses.)
    Note: this version will not work on Trinket M0, and is committed as is to keep track of historical changes!
    [code.py, schedule.py]
2020-07-18 CircuitPython Controller: fix to work on Trinket M0.
    Trinket M0 does not support `time.time()`, but does support
    `time.monotonic()`, which is also in seconds and works fine for the need of
    the program. But on the other hand, `monotonic()` returns a floating point
    value.
    Also correct the detection of the MCP23017, and raise an exception if no
    expander is found at all.
    [code.py]
2020-07-18 Set up isort for CircuitPython code.
    The special CircuitPython configuration of isort is meant to separate the
    Python standard library modules from CP (or Blinka) modules in the
    sections, for ease of reading.
2020-07-21 Add a new revision for the actuator board.
    Rotate the board so that the writing is in the same orientation as the controller board once mounted.
    Include +5/GND markings on both connectors.
    Put the MCU connector on the _bottom_ layer, rather than the top.
    [pth.brd, pth.sch]
2020-07-21 Update the test board.
    The new revision is smaller, and reports the connector on the bottom side as expected.
    [test-board.brd, test-board.sch]
2020-07-24 Re-layout board to align with actuator.
    Also update the microUSB connector to a SnapEDA symbol for an Amphenol connector that appears to be easier to source and solder.
    [basic.brd, basic.sch]
2020-07-24 Update components and layout for 8051 board.
    Replace the microUSB connector to be the same Amphenol part as used in the ATmega board.
    Replace the single electrolytic with a ceramic capacitor, and match the footprint between that and the CP2104 one.
    [basic.brd, basic.sch]
2020-07-26 Replace the wima capacitor object with a generic one.
    This is pretty much the same footprint (except the solder pad is slightly thinner), but it requires one less library, since the xtal's capacitors are coming from rcl as well.
    [basic.brd, basic.sch]
2020-07-26 Clean up the Trinket M0 based boards.
    This makes the two board use the same size, and the same positioning of the common components.
    It also reorients the silkscreen markings on the back to have the same orientation as the actuator board.
    Also mark the used lines from the Trinket, as you can technically use any other MCU that can drive I²C.
    [trinket-mcp23016.brd, trinket-mcp23016.sch, trinket-mcp23017.brd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]
2020-07-26 Expand documentation.
    Includes some commentary around the boards, and a link to one of the pictures to explain what this is all about.
2020-07-26 Make the text fit into the silkscreen.
    [trinket-mcp23016.brd, trinket-mcp23017.brd]
2020-07-26 Align the resistor label.
    [trinket-mcp23017.brd]
2020-07-26 Update the capacitor to match the 8051 board.
    [trinket-mcp23016.brd, trinket-mcp23016.sch]
2020-08-16 Add an ATmega48 based firmware.
    This is based on the board designs in eagle-boards/atmega/ and the original
    8051 firmware.
    Unlike the STC89C52, the ATmega48 MCU has non-linear mapping of the I/Os,
    which makes the room definition a bit more complicated, but otherwise the
    logic of the code is essentially the same.
    Note that the "strobe" test has been removed from this version, because
    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
2020-08-16 Update documentation of ATmega48 board, now that it was tested.
2020-08-16 Remove the "strobe mode" test, as done on the atmega48 firmware.
    The strobe mode is unsafe, as it routes multiple LEDs for the same room
    into the same collector of the Darlington arrays.
2020-08-16 Fix pre-commit configuration to ignore trailing whitespace on Eagle boards.
2020-08-16 Backport the ATmega48 changes to the CircuitPython version.
    This includes removing the knuckle pattern (unsafe), and introducing the 1
    second power-on self-test.

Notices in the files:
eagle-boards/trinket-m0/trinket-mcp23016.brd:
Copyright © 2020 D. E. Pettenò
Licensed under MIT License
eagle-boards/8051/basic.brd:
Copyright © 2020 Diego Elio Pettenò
